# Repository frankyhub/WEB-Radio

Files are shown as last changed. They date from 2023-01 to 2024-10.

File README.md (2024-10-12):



<div align="center">

|[:skull:ISSUE](https://github.com/frankyhub/WEB-Radio/issues?q=is%3Aissue)|[:speech_balloon: Forum /Discussion](https://github.com/frankyhub/WEB-Radio/discussions)|[:grey_question:WiKi](https://github.com/frankyhub/WEB-Radio/wiki)||
|--|--|--|--|
| | | | |
||<a href="https://github.com/frankyhub/WEB-Radio/issues">|<a href="https://github.com/frankyhub/WEB-Radio/discussions">|<a href="https://github.com/frankyhub/WEB-Radio/releases">|
|| <a href="https://github.com/frankyhub/WEB-Radio/pulse" alt="Activity">| <a href="https://github.com/frankyhub/WEB-Radio/graphs/traffic">  |<a href="https://github.com/frankyhub?tab=stars"> |
</div>

# WEB-Radio

Dieses Repository beinhaltet die Dateien eines WEB Radios. Über einen Drehgeber Encoder sind 20 Radiostationen wählbar. Die Lautstärke wird direkt über das Poti am Audio-Verstärker eingestellt. Das LCD-Display zeigt die gewählte Radio-Station an. Die Radio-Stationen sind über einen WEB-Server abruf- und veränderbar.<br>
Nach dem Einschalten über den Volume-Regler/Schalter, sucht der Mikrocontroller nach einer gültigen WLAN-Verbindung und stellt die zuletzt gewählte Radio-Station ein. Liegt keine gültige WLAN-Verbindung vor, startet der WLAN-Manager. Über die Netzwerkeinstellung des Handys/Tablet kann nach der Auswahl „WEBRADIO“ der WLAN-Manager mit der IP-Adresse 192.168.4.1 aufgerufen werden. Über den WLAN-Manager sind die eigenen WLAN-Zugangsdaten speicherbar. Nach dem speichern der Zugangsdaten startet der Mikrocontroller neu und das LCD-Display zeigt die IP-Adresse des WEB-Servers und danach die gewählte Radio-Station an.

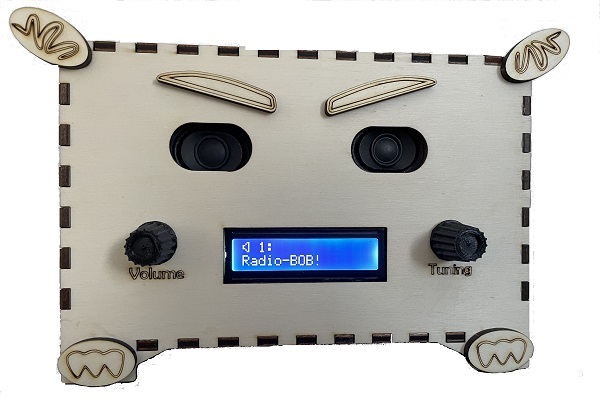
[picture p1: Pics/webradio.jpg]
webradio1


WEB-Radio WiFi-Einstellung

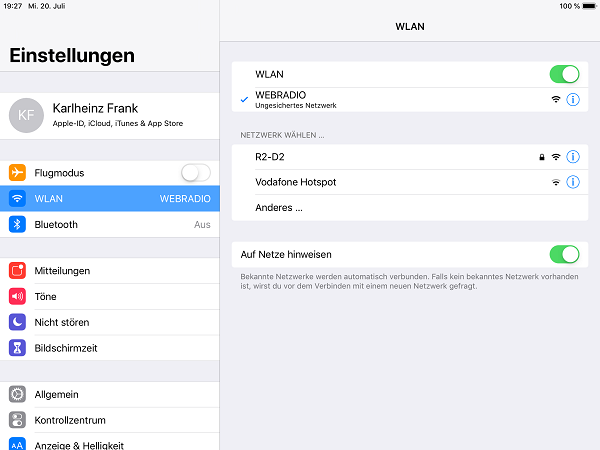
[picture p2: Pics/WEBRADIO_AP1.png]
webradio2


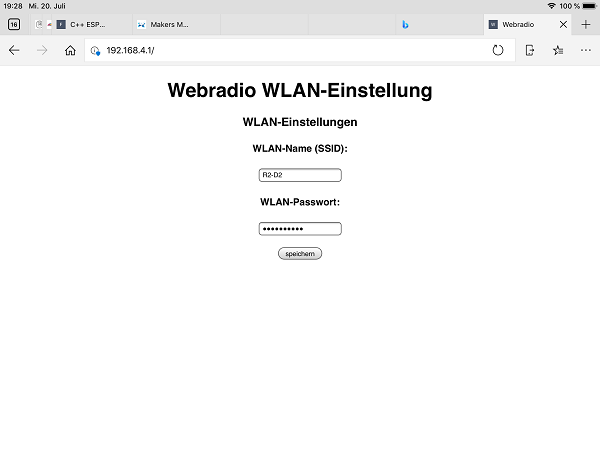
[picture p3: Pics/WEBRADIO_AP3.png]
webradio2


WEB-Radio LCD Display

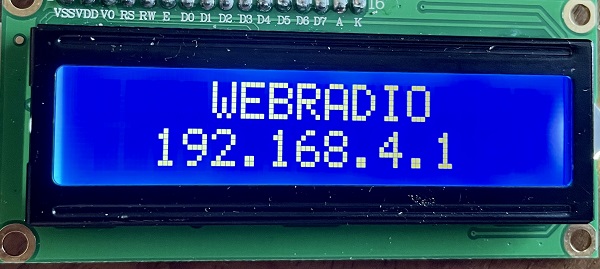
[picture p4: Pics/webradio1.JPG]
webradio2


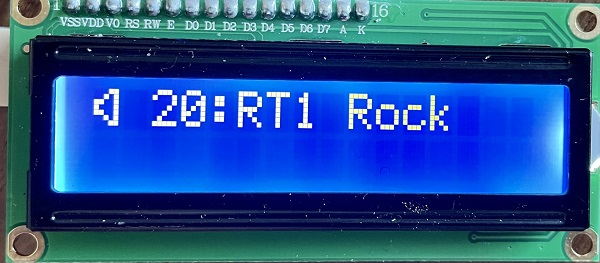
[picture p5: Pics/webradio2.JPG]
webradio2


WEB-Radio WEB-Server Senderliste

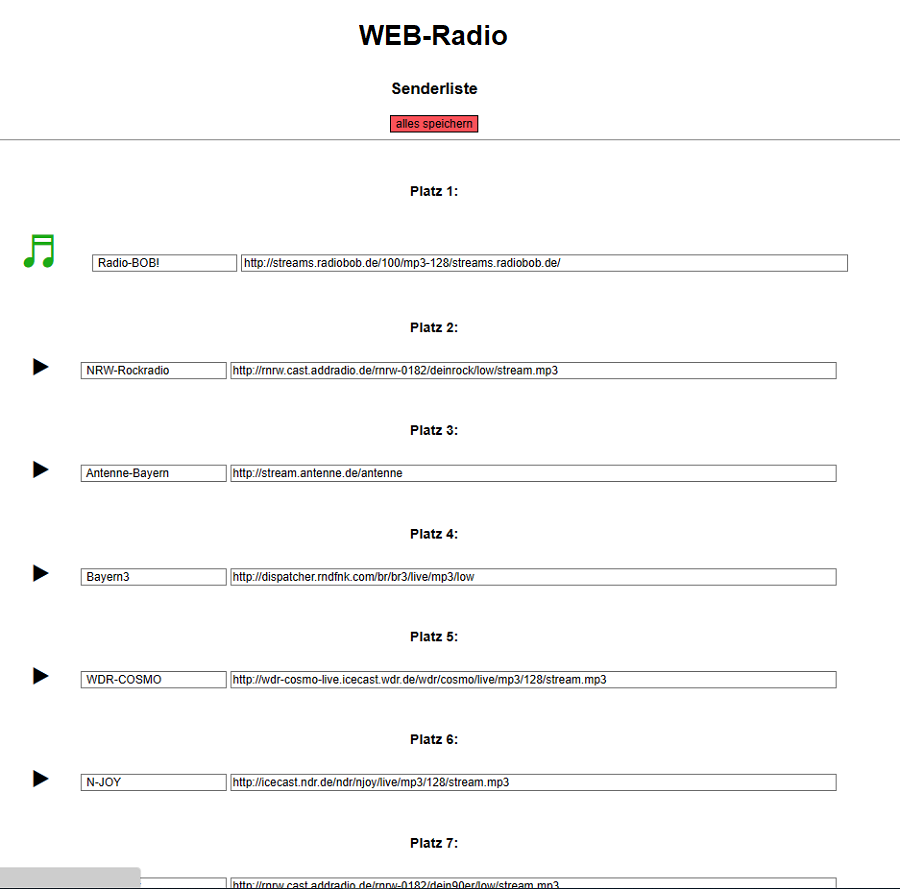
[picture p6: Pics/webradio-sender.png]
webradio2


WEB-Radio Verdrahtung

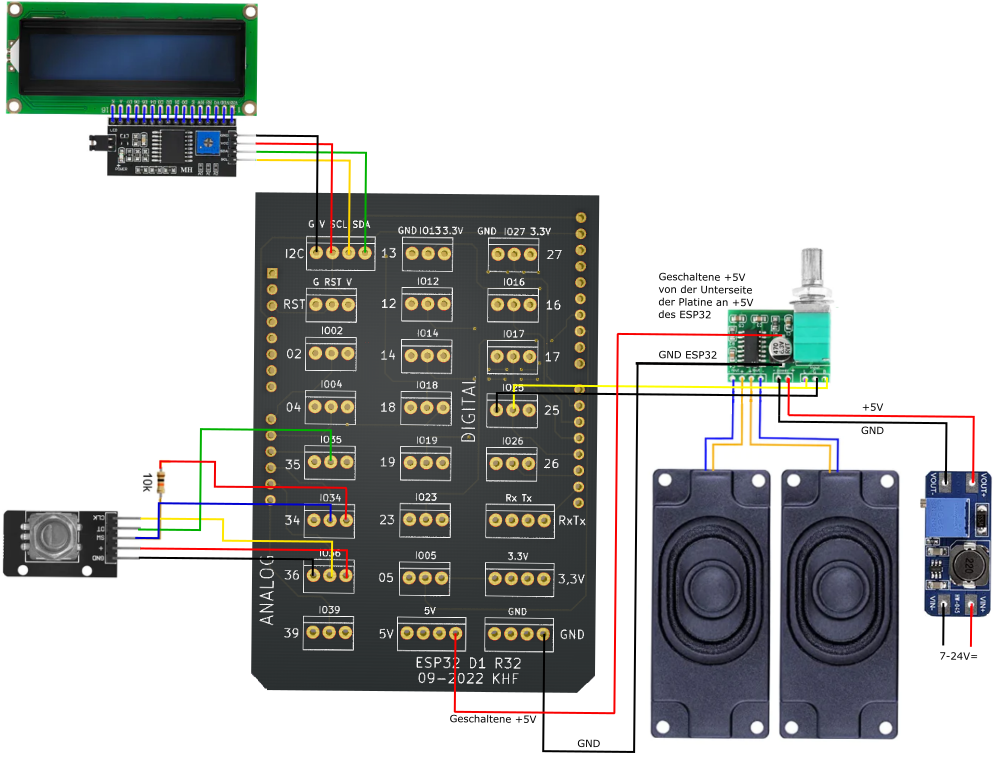
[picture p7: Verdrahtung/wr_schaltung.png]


---

<div style="position:absolute; left:2cm; ">   
<ol class="breadcrumb" style="border-top: 2px solid black;border-bottom:2px solid black; height: 45px; width: 900px;"> <p align="center"><a href="#oben">nach oben</a></p></ol>
</div>  

---

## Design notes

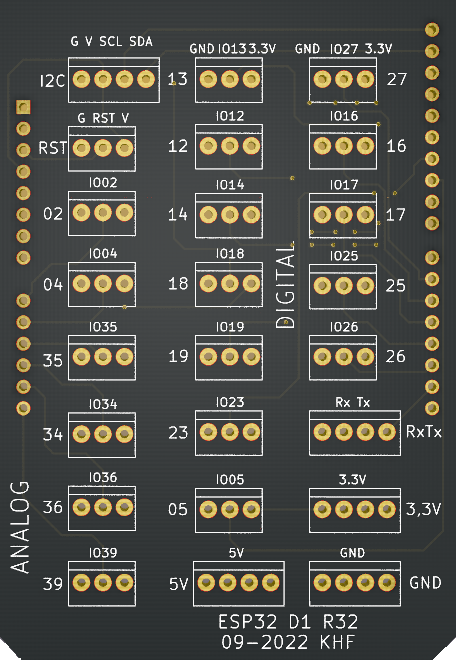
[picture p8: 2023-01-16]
Pics/Shield.png

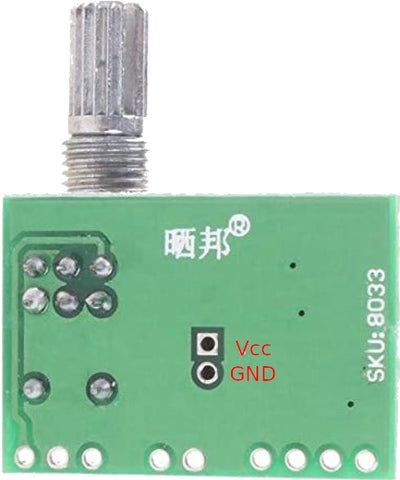
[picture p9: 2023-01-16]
Pics/audioverstärker.jpg

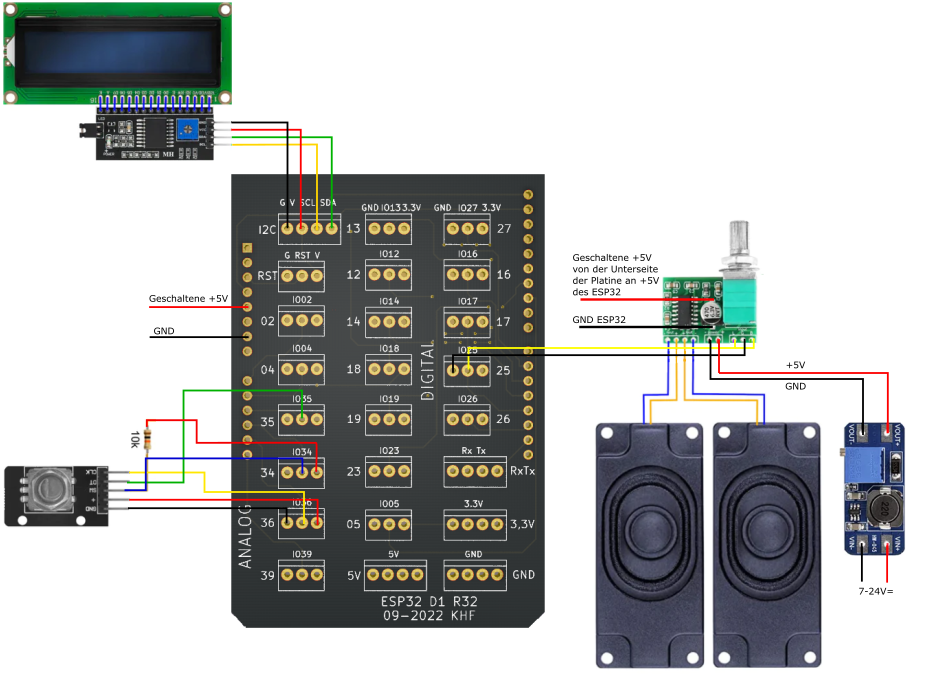
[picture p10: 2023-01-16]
Pics/Verdrahtung Iradio.png

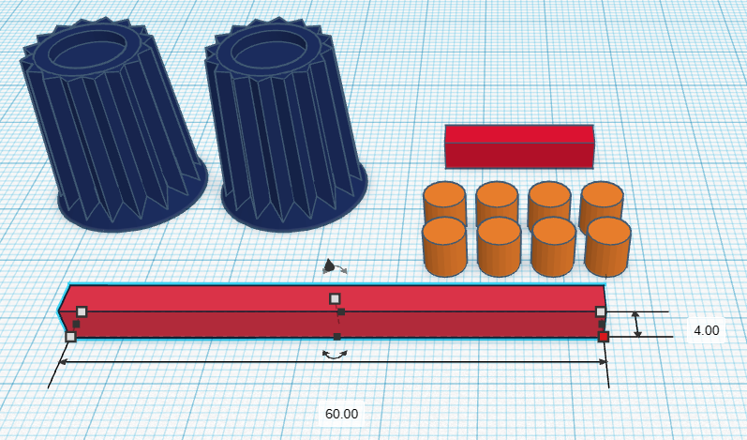
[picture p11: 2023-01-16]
Pics/3D-Druck.png

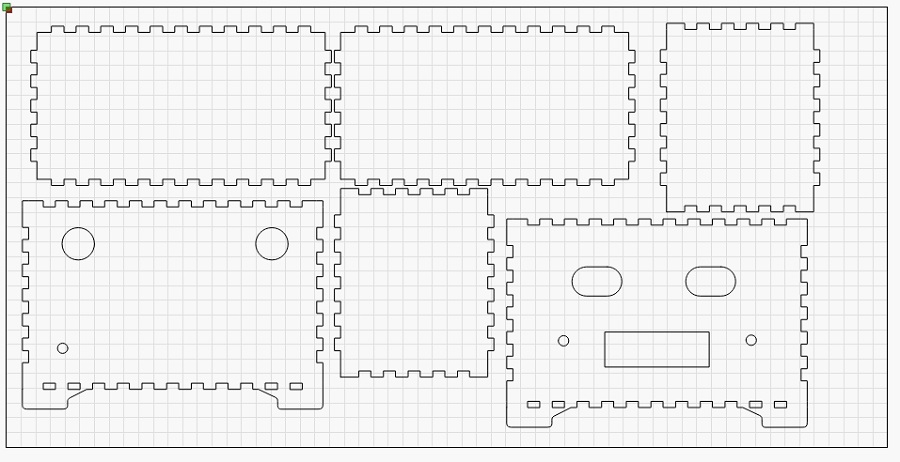
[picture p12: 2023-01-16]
Pics/webradio_gehäuse.jpg

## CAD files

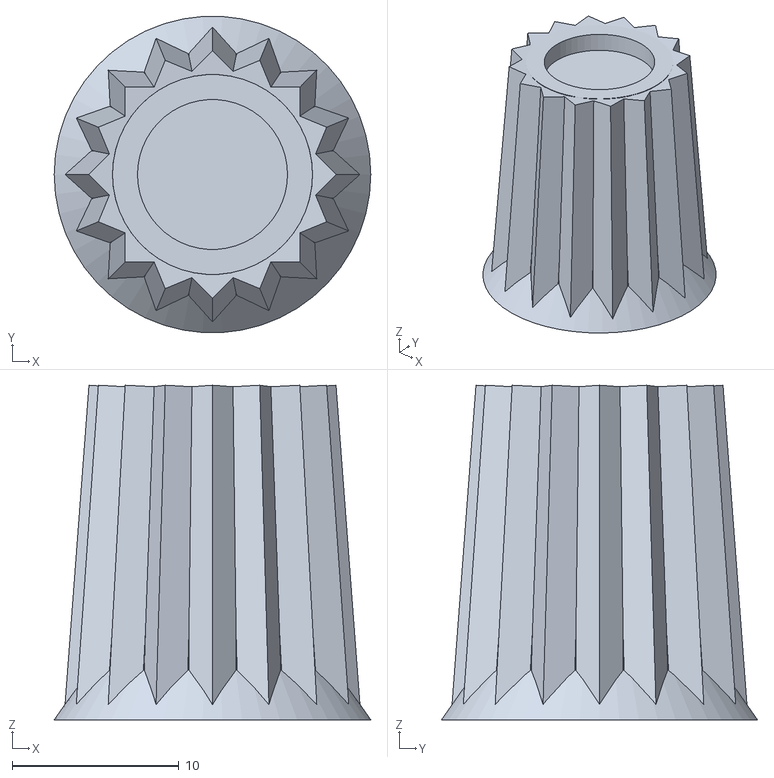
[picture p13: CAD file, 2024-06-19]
3D/Stellknopf_6-1.stl
19.0 x 19.0 x 20.1

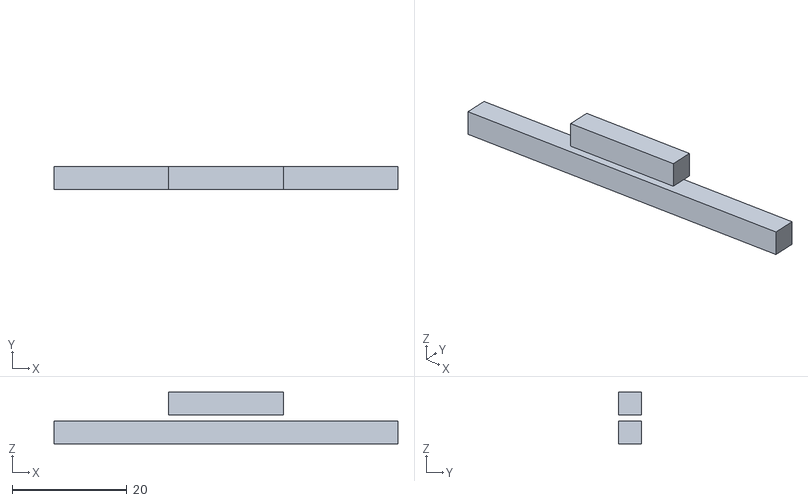
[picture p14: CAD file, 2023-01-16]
3D/LCD 4x4.stl
60.0 x 4.00 x 9.00

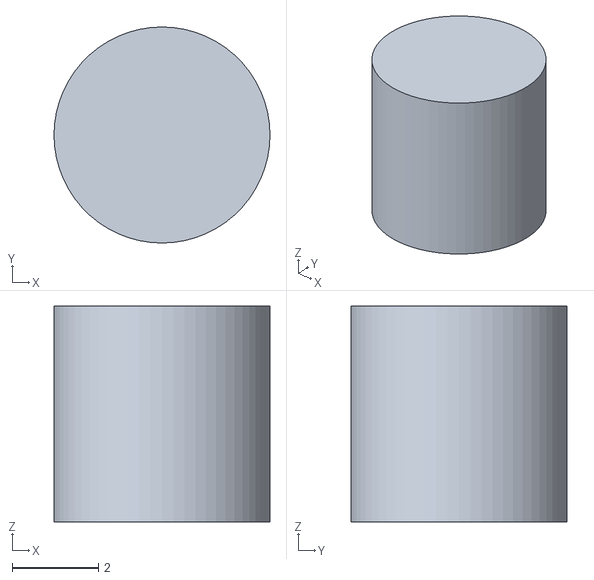
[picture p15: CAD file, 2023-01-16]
3D/Pin 5x5.stl
5.00 x 5.00 x 5.00

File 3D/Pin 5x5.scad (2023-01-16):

$fn=60;
cylinder(h=5,d=5);

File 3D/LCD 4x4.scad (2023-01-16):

$fn=60;
cube(size = [60,4,4], center = true);

translate([0,5,0])
cube(size = [20,4,4], center = true);

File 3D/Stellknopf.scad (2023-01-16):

/*
*******************************************
Objekt Info: Poti Drehknopf

*******************************************
Version: 16.01.2023 khf
*******************************************
*/

//***************   Auswahl   *************
// Form der Oberseite des Knopfes.  Der Typ "Einbau" kann lackiert werden.
CapType = 1;	// [0:Flach, 1:Einbau, 2:Dome]

// Möchtest du einen großen StilZeiger?
TimerKnob=0;	// [0:Nein, 1:Ja]

// Möchtest du eine Markierung oben, um die Richtung anzuzeigen?
Pointer1 = 0;	// [0:Nein, 1:Ja]

// Möchtest du einen Richtungszeiger?
Pointer2 = 0;	// [0:Nein, 1:Ja]

// Willst du einen Rändelung um den Knopf?
Knurled = 1;	// [0:Nein, 1:Ja]

//***************   Libraries  ************

//keine

//*****************************************

//***************  Parameter   *************
$fn=80;

// Loch-Durchmesser in mm.
HoleDiameter = 6.1;

// Tiefe des Lochs im Boden (in mm). 
HoleDepth = 18;

// Wenn du ein D-förmiges Loch wünscht, stelle die Dicke auf der flachen Seite (in mm) ein.  Größere Werte für die Ebene machen das Loch kleiner.
HoleFlatThickness = 0;

// Höhe (in mm).  Wenn die Kuppelkappe ausgewählt ist, ist sie nicht in der Höhe enthalten.  Auch die Wellenlänge wird nicht gezählt.
KnobHeight = 20;

// Durchmesser des Knopfes in mm.  
KnobDiameter = 15;

// 0 = Verjüngung
TaperPercentage = 20;		// [0:0%, 10:10%, 20:20%, 30:30%, 40:40%, 50:50%]

// Breite des Rings "Dial" (in mm).  0= keine RIng
RingWidth = 2;

// Die Anzahl der Markierungen auf dem Zifferblatt.  0 = keine Markierungen   (RingWidth muss ungleich Null sein.)
RingMarkings = 0;

// Durchmesser des Lochs für die Befestigungsschraube in mm.  0 = kein Loch
ScrewHoleDiameter = 0;

//  Länge der Welle auf der Unterseite des Knopfes (in mm).  0 = keine Welle
ShaftLength = 0;

// Durchmesser der Welle auf der Unterseite des Knopfes in mm.  (ShaftLength größer Null sein.)
ShaftDiameter = 10;

// Möchtest du eine Kerbe in der Welle?  Es kann für einen Einpressknopf verwendet werden (anstelle einer Befestigungsschraube).  (ShaftLength größer Null sein.)
NotchedShaft = 0;	// [0:No, 1:Yes]


//*****************************************

//**************   Programm  **************

//////////////////////////
//Erweiterte Einstellungen
//////////////////////////

RingThickness = 5*1;
DivotDepth = 1.5*1;
MarkingWidth = 1.5*1;
DistanceBetweenKnurls = 3*1;
TimerKnobConst = 1.8*1;

//////////////////////////
//Berechnungen
//////////////////////////

PI=3.14159265*1;
KnobMajorRadius = KnobDiameter/2;
KnobMinorRadius = KnobDiameter/2 * (1 - TaperPercentage/100);
KnobRadius = KnobMinorRadius + (KnobMajorRadius-KnobMinorRadius)/2;
KnobCircumference = PI*KnobDiameter;
Knurls = round(KnobCircumference/DistanceBetweenKnurls);
Divot=CapType;

TaperAngle=asin(KnobHeight / (sqrt(pow(KnobHeight, 2) +
		pow(KnobMajorRadius-KnobMinorRadius,2)))) - 90;

DivotRadius = KnobMinorRadius*.4;

difference() {
union()
{
translate([0, 0, (ShaftLength==0)? 0 : ShaftLength-0.001])
difference()
{
union()
{
	// Primary knob cylinder
	cylinder(h=KnobHeight, r1=KnobMajorRadius, r2=KnobMinorRadius,
			$fn=50);
	
	if (Knurled)
		for (i=[0 : Knurls-1])
			rotate([0, 0, i * (360/Knurls)])
				translate([KnobRadius, 0, KnobHeight/2])
					rotate([0, TaperAngle, 0]) rotate([0, 0, 45])
						cube([2, 2, KnobHeight+.001], center=true);

 	if (RingMarkings>0)
		for (i=[0 : RingMarkings-1])
			rotate([0, 0, i * (360/RingMarkings)])
				translate([KnobMajorRadius + RingWidth/2, 0, 1])
					cube([RingWidth*.5, MarkingWidth, 2], center=true);		
	
	if (Pointer2==1)
		translate([KnobRadius, 0, KnobHeight/2-2])
			rotate([0, TaperAngle, 0])
				cube([8, 3, KnobHeight], center=true);		

	if (RingWidth>0)
		translate([0, 0, RingThickness/2])
			cylinder(r1=KnobMajorRadius + RingWidth, r2=KnobMinorRadius,
					h=RingThickness, $fn=50, center=true);

	if (Divot==2)
		translate([0, 0, KnobHeight])
			difference()
			{
				scale([1, 1, 0.5])
					sphere(r=KnobMinorRadius, $fn=50, center=true);

				translate([0, 0, 0-(KnobMinorRadius+.001)])
					cube([KnobMinorRadius*2.5, KnobMinorRadius*2.5,
							KnobMinorRadius*2], center=true);
			}

	if (TimerKnob==1) intersection()
		{
			translate([0, 0, 0-(KnobDiameter*TimerKnobConst) + KnobHeight])
			sphere(r=KnobDiameter*TimerKnobConst, $fn=80, center=true);		
	
			translate([0-(KnobDiameter*TimerKnobConst)*0.1, 0,
					KnobHeight/2])
				scale([1, 0.5, 1])
					cylinder(h=KnobHeight, r=(KnobDiameter*TimerKnobConst) *
							0.8, $fn=3, center=true);
		}
}

// Zeiger1
if (Pointer1==1)
	translate([KnobMinorRadius*.55, 0, KnobHeight + DivotRadius*.6])
		sphere(r=DivotRadius, $fn=40);

// Divot1: Zentrierter zylynischer Divot
if (Divot==1)
	translate([0, 0, KnobHeight])
		cylinder(h=DivotDepth*2, r=KnobMinorRadius-1.5, $fn=50,
				center=true);

if (ShaftLength==0)
{
	// Loch für die Welle
	translate([0, 0, HoleDepth/2 - 0.001])
		difference()
		{
			cylinder(r=HoleDiameter/2, h=HoleDepth, $fn=20,
					center=true);
	
			// D-förmiges Loch
			translate([(0-HoleDiameter)+HoleFlatThickness, 0, 0])
				cube([HoleDiameter, HoleDiameter, HoleDepth+.001],
						center=true);
		}
	
	// Loch für die Befestigungsschraube
	if (ScrewHoleDiameter>0)
		translate([0 - (KnobMajorRadius+RingWidth+1)/2, 0,
				HoleDepth/2])
			rotate([0, 90, 0])
			cylinder(h=(KnobMajorRadius+RingWidth+1),
					r=ScrewHoleDiameter/2, $fn=20, center=true);
}

// Stelle sicher, dass die unteren Enden bei z=0 sind
translate([0, 0, -10])
	cube([(KnobMajorRadius+RingWidth) * 3,
			(KnobMajorRadius+RingWidth) * 3, 20], center=true);
}

if (ShaftLength>0)
	difference()
	{
		translate([0, 0, ShaftLength/2])
			cylinder(h=ShaftLength, r=ShaftDiameter/2, $fn=20,
					center=true);

		if (NotchedShaft==1)
		{
			cube([HoleDiameter/2, ShaftDiameter*2, ShaftLength],
					center=true);
		}

		// Loch für die Welle
		translate([0, 0, HoleDepth/2 - 0.001])
			difference()
			{
				cylinder(r=HoleDiameter/2, h=HoleDepth, $fn=20,
						center=true);
		
				// D-förmiges Loch
				translate([(0-HoleDiameter)+HoleFlatThickness, 0, 0])
					cube([HoleDiameter, HoleDiameter, HoleDepth+.001],
							center=true);
			}
		
		// Loch für die Befestigungsschraube
		if (ScrewHoleDiameter>0)
			translate([0 - (KnobMajorRadius+RingWidth+1)/2, 0,
					HoleDepth/2])
				rotate([0, 90, 0])
				cylinder(h=(KnobMajorRadius+RingWidth+1),
						r=ScrewHoleDiameter/2, $fn=20, center=true);
	}
}


translate(v = [0, 0, 1]) { 
cylinder(h = 5, r1 = 6, r2 = 6, center = true);
}
translate(v = [0, 0, 4]) { 
cylinder(h = 6, r1 = 3, r2 = 3, center = true);
    }
}

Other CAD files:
3D/Stellknopf.stl

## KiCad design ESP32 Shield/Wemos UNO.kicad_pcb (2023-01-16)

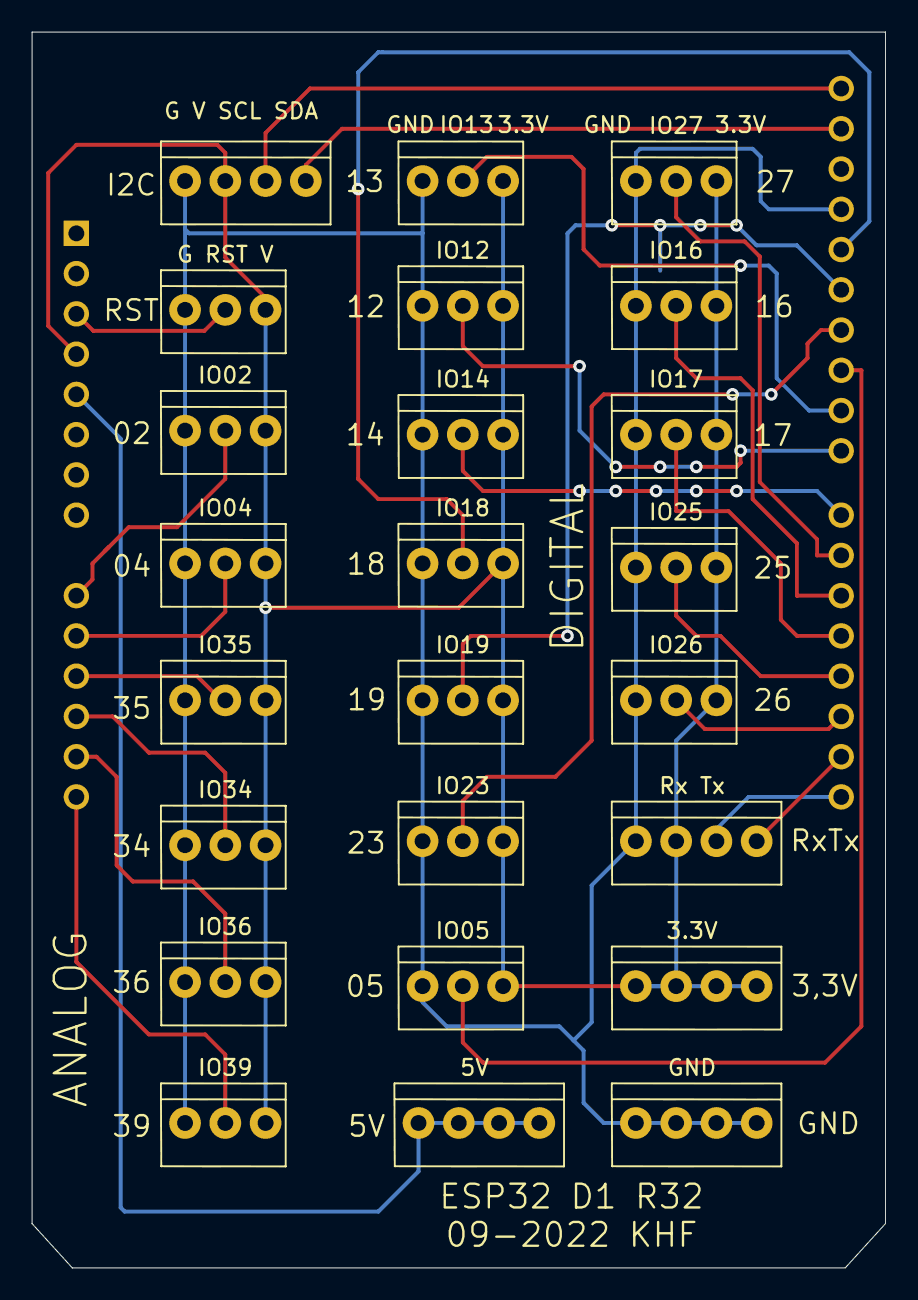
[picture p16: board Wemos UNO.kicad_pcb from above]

Board: 2 copper layers, 53.8 x 78.0 mm, 25 parts (1 on the bottom side), 26 nets.

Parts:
3.3V, 5V: PL-Stecker_4pol_Data; PL-Stecker
A1: Arduino_UNO_R3
G RST V: PL-Stecker_3pol; PL-Stecker3pol
G V SCL SDA: PL-Stecker_4pol_I2C; PL-Stecker
GND: PL-Stecker_4pol_Data; PL-Stecker
IO02, IO04, IO05, IO12, IO13, IO14, IO16, IO17, IO18, IO19, IO23, IO25, IO26, IO27, IO34, IO35, IO36, IO39: PL-Stecker_3pol; PL-Stecker3pol
Rx Tx: PL-Stecker_4pol_I2C; PL-Stecker

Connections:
unnamed: A1.3, G RST V.2
unnamed: 3.3V.1, 3.3V.2, 3.3V.3, 3.3V.4, A1.4, G RST V.3, G V SCL SDA.2, IO02.3, IO04.3, IO05.3, IO12.3, IO13.3, IO14.3, IO16.3, IO17.3, IO18.3, IO19.3, IO23.3, IO25.3, IO26.3, IO27.3, IO34.3, IO35.3, IO36.3, IO39.3, Rx Tx.2
unnamed: 5V.1, 5V.2, 5V.3, 5V.4, A1.5
unnamed: A1.9, IO02.2
unnamed: A1.10, IO04.2
unnamed: A1.11, IO35.2
unnamed: A1.12, IO34.2
unnamed: A1.13, IO36.2
unnamed: A1.14, IO39.2
unnamed: A1.15, Rx Tx.3
unnamed: A1.16, Rx Tx.4
unnamed: A1.17, IO26.2
unnamed: A1.18, IO25.2
unnamed: A1.19, IO17.2
unnamed: A1.20, IO16.2
unnamed: A1.21, IO27.2
unnamed: A1.22, IO14.2
unnamed: A1.23, IO12.2
unnamed: A1.24, IO13.2
unnamed: A1.25, IO05.2
unnamed: A1.26, IO23.2
unnamed: A1.27, IO19.2
unnamed: A1.28, IO18.2
unnamed: A1.29, G RST V.1, G V SCL SDA.1, GND.1, GND.2, GND.3, GND.4, IO02.1, IO04.1, IO05.1, IO12.1, IO13.1, IO14.1, IO16.1, IO17.1, IO18.1, IO19.1, IO23.1, IO25.1, IO26.1, IO27.1, IO34.1, IO35.1, IO36.1, IO39.1, Rx Tx.1
unnamed: A1.31, G V SCL SDA.4
unnamed: A1.32, G V SCL SDA.3

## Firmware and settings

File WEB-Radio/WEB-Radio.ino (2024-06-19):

/*************************************************************************************************
                                      PROGRAMMINFO
**************************************************************************************************
Funktion: ESP32 WEB-Radio - WEB-Server - AP-WLAN Config
Senderliste: https://rrradio.de/radiosender/
**************************************************************************************************
Version: 15.01.2023
**************************************************************************************************
Board: ESP32vn IoT UNO  V1.0.6
**************************************************************************************************
Libraries:
ai-esp32-rotary-encoder-master
LiquidCrystal_I2C-master
**************************************************************************************************
C++ Arduino IDE V1.8.19
**************************************************************************************************
Einstellungen:
https://dl.espressif.com/dl/package_esp32_index.json
http://dan.drown.org/stm32duino/package_STM32duino_index.json
http://arduino.esp8266.com/stable/package_esp8266com_index.json
*************************************************************************************************

 * WEB-Radio
 * Following Parts:
 * - audio          : streaming and decoding audio data
 * - lcdisplay      : show station data an LCD
 * - rotary         : initialize and handle choosing senders
 * - senderlist     : senderlist by flash-values - or, if not present, by defaults
 * - senderconfig   : asynchronus webinterface to store sendernames und -urls
 *   senderconf.h   : html-template for above
 * - wlanconfig     : seperate program to get WLAN-config per webinterface
 *   wlanconf.h     : html-template for above
 *   
 *   Used libraries (included in their parts): 
 *   - ESPwebRadio  : Preferences.h
 *   - audio        : ESP8266audio (AudioFileSourceICYStream.h, AudioFileSourceBuffer.h, AudioGeneratorMP3.h, AudioOutputI2S.h)
 *   - lcdisplay    : LiquidCrystal_I2C.h
 *   - rotary       : AiEsp32RotaryEncoder.h
 *   - senderconfig : ESPAsyncWebServer.h, Preferences.h
 *   - wlanconfig   : WiFi.h, Preferences.h, ESPAsyncWebServer.h
 */

#include <Preferences.h>

//structure for stationlist
typedef struct {
  char url[100];  //stream url
  char name[100]; //stations name
} Station;

#define STATIONS 21 //0-21 number of available stations

//station list (stations can now be modified by webinterface)
Station stationlist[STATIONS];

//instances of prefernces
Preferences pref;
Preferences sender;

//global variables
uint8_t curStation = 0;   //index for current selected station in stationlist
uint8_t actStation = 0;   //index for current station in station list used for streaming 
uint32_t lastchange = 0;  //time of last selection change


//setup
void setup() {
  Serial.begin(115200);
  delay(1000);
  
  // -------------------
  setup_senderList();
  setup_audio();
  setup_rotary();
  setup_lcdisplay();
  //init WiFi
  Serial.println("Connecting to WiFi");
  while (!makeWLAN()) {
    Serial.println("Cannot connect :(");
    delay(1000);
  }
  Serial.println("Connected");
  setup_senderConfig();
  // -------------------

  //set current station to 0
  curStation = 0;
  //start preferences instance
  pref.begin("radio", false);
  //set current station to saved value if available
  if (pref.isKey("station")) curStation = pref.getUShort("station");
  //set active station to current station 
  //show on display and start streaming
  actStation = curStation;
  showStation();
  startUrl();
}

// main loop
void loop() {
  //check if stream has ended normally not on ICY streams
  if (!loop_audio()) {
    Serial.printf("MP3 done\n");

    // Restart ESP when streaming is done or errored
    delay(10000);

    ESP.restart();
  }
  //read events from rotary encoder
  rotary_loop();

}

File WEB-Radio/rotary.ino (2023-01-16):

//library for rotary encoder
#include "AiEsp32RotaryEncoder.h"

//used pins for rotary encoder
#define ROTARY_ENCODER_A_PIN 35 //33
#define ROTARY_ENCODER_B_PIN 36 //32
#define ROTARY_ENCODER_BUTTON_PIN 34
#define ROTARY_ENCODER_VCC_PIN -1 /* 27 put -1 of Rotary encoder Vcc is connected directly to 3,3V; else you can use declared output pin for powering rotary encoder */

//depending on your encoder - try 1,2 or 4 to get expected behaviour
//#define ROTARY_ENCODER_STEPS 1
//#define ROTARY_ENCODER_STEPS 2
#define ROTARY_ENCODER_STEPS 4

//instance for rotary encoder
AiEsp32RotaryEncoder rotaryEncoder = AiEsp32RotaryEncoder(ROTARY_ENCODER_A_PIN, ROTARY_ENCODER_B_PIN, ROTARY_ENCODER_BUTTON_PIN, ROTARY_ENCODER_VCC_PIN, ROTARY_ENCODER_STEPS);

// to be called in 'loop()'
//handle events from rotary encoder
void rotary_loop()
{
  //dont do anything unless value changed
  if (rotaryEncoder.encoderChanged())
  {
    uint16_t v = rotaryEncoder.readEncoder();
    Serial.printf("Station: %i\n",v);
    //set new currtent station and show its name
    if (v < STATIONS) {
      curStation = v;
      showStation();
      lastchange = millis();
    }
  }
  //if no change happened within 10s set active station as current station
  if ((lastchange > 0) && ((millis()-lastchange) > 10000)){
    curStation = actStation;
    lastchange = 0;
    showStation();
  }
  //react on rotary encoder switch
  if (rotaryEncoder.isEncoderButtonClicked())
  {
    //set current station as active station and start streaming
    actStation = curStation;
    Serial.printf("Active station %s\n",stationlist[actStation].name);
    pref.putUShort("station",curStation);
    startUrl();
    //call show station to display the speaker symbol
    showStation();
  }
}

//interrupt handling for rotary encoder
void IRAM_ATTR readEncoderISR()
{
  rotaryEncoder.readEncoder_ISR();
}

// to be called in 'setup()'
void setup_rotary()
{
  //start rotary encoder instance
  rotaryEncoder.begin();
  rotaryEncoder.setup(readEncoderISR);
  rotaryEncoder.setBoundaries(0, STATIONS, true); //minValue, maxValue, circleValues true|false (when max go to min and vice versa)
  rotaryEncoder.disableAcceleration();  
}
